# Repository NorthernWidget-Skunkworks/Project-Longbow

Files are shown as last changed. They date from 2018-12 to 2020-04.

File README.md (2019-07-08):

# Project-Longbow
Eagle files for a RS-485 range extender system, designed to go between I2C and RS-485 (or simply convert RS-485 to UART. Designed to work in unison with TP-Downhole Longbow system from Northern Widget

<br>
<br />This work is licensed under a <a rel="license" href="http://creativecommons.org/licenses/by-sa/4.0/">Creative Commons Attribution-ShareAlike 4.0 International License</a>.

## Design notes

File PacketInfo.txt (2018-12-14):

Packet Length:

Send:
SOF - 1
ADR - 2
RegID - 2
EOF - 1

Total: 6

Rec:
SOF - 1
ADR - 2
RegID - 2
Data - 10
Format - 1
CRC - 3
EOF - 1

Total: 19

Longbow Widget Register Map

Ctrl:
0 - Turn on UART
1 - Send, when set, input registers are written over serial
2 - Sleep mode (??)
3 - Packet validity (CRC check result)

7 - Reset

Baud:
0 ~ 8 - Baud rate setting bits (Baud Rate = Baud*1200)

I2C send data:

I2C.beginTransmission();
I2C.write(ADR);
I2C.endTransmission();

I2C.beginTransmission();
I2C.write(ADR);
I2C.endTransmission();

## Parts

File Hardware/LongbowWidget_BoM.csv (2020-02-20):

Qty | Value | Device | Package | Parts | Description | DIGIKEY | MF | MOUSER | MPN | VALUE | VALUE_PART
2 |  | TVSSM712 | SOT23-3 | D1, D2 | Generic dual channel TVS diode | CDSOT23-SM712CT-ND | Bourns |  | CDSOT23-SM712
3 | 0.1uF | C-EU0.1UFC0402 | C0402 | C3, C4, C5 | CAPACITOR, European symbol | 490-4759-1-ND | Murata |  | GCM155R71C104KA55D
2 | 100R | R-EU_100R0402 | R0402 | R1, R2 | RESISTOR, European symbol | 311-100LRCT-ND | Yageo |  | RC0402FR-07100RL |  | 100
4 | 10R | R-EU_R0603 | R0603 | R10, R11, R12, R13 | RESISTOR, European symbol | 541-10.0SCT-ND | Vishay |  | CRCW060310R0FKEAHP |  | 10
5 | 10k | R-EU_10KR0402 | R0402 | R3, R4, R5, R8, R9 | RESISTOR, European symbol | 311-10KJRCT-ND | Yageo |  | RC0402JR-0710KL |  | 10k
2 | 1uF | C-EU1UFC0603 | C0603 | C1, C2 | CAPACITOR, European symbol | 490-10479-1-ND | Murata |  | GRM188R61C105KA12D
1 | ATTINY441/841VQFN | ATTINY441/841VQFN | VQFN-20 | U$2 | ATtiny841/441 8 bit AVR Microcontroller | ATTINY841-MMHRCT-ND | Atmel |  | ATTINY841-MMHR
1 | AVRISP1.27MM | AVRISP1.27MM | 2X3_1.27 | ISP1 | AVR ISP HEADER
2 | CONN_6SCREW_2.54 | CONN_6SCREW_2.54 | 1X06_SCREW | J0, J1 | Genaric 6 pin header | ED10565-ND | OnShore |  | OSTVN06A150
1 | DMG3404 | MOSFET-NCH-DMG3404L | SOT23-3 | Q2 | N-channel MOSFETs | DMG3404L-7DICT-ND | Diodes Incorporated |  | DMG3404L-7 | DMG3404
2 | JUMPER-SMT_2_NO_SILK | JUMPER-SMT_2_NO_SILK | SMT-JUMPER_2_NO_SILK | JP1, JP2 | Normally open jumper
1 | MIC94090C6 | MIC94090C6 | SC-70_6 | U$1 | MIC94090 - Hight Side Load Switch | 576-3484-1-ND | Microchip |  | MIC94090YC6-TR
1 | NWLOGO_MED | NWLOGO_MED | NWLOGO_MED | U$4 | Medium-sized Northern Widget logo
1 | SN65HVD33RHL | SN65HVD33RHL | VQFN-20_POWER | U2 | SN65HVD33 - Full Duplex RS-485 Tranciver, with output enable | 296-24087-1-ND | TI |  | SN65HVD33RHLR
1 | TPS7A0533DBV | TPS7A0533DBV | SOT23-5 | U1 | TPS7A05* - Ultra Low Power Low Dropout Linear Regulator | 296-TPS7A0533PDBVRCT-ND | TI | 595-TPS7A0533PDBVR | TPS7A0533PDBVR
2 | TXS0102DQM | TXS0102DQM | DQM_R-PX2SON-N8 | U$3, U$6 | TXS0102 - 2 Channel Bidirectional Voltage Level Translator | 296-28435-1-ND | TI |  | TXS0102DQMR

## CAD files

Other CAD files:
3Dprint/StencilMount_LongbowWidget_v1.STL

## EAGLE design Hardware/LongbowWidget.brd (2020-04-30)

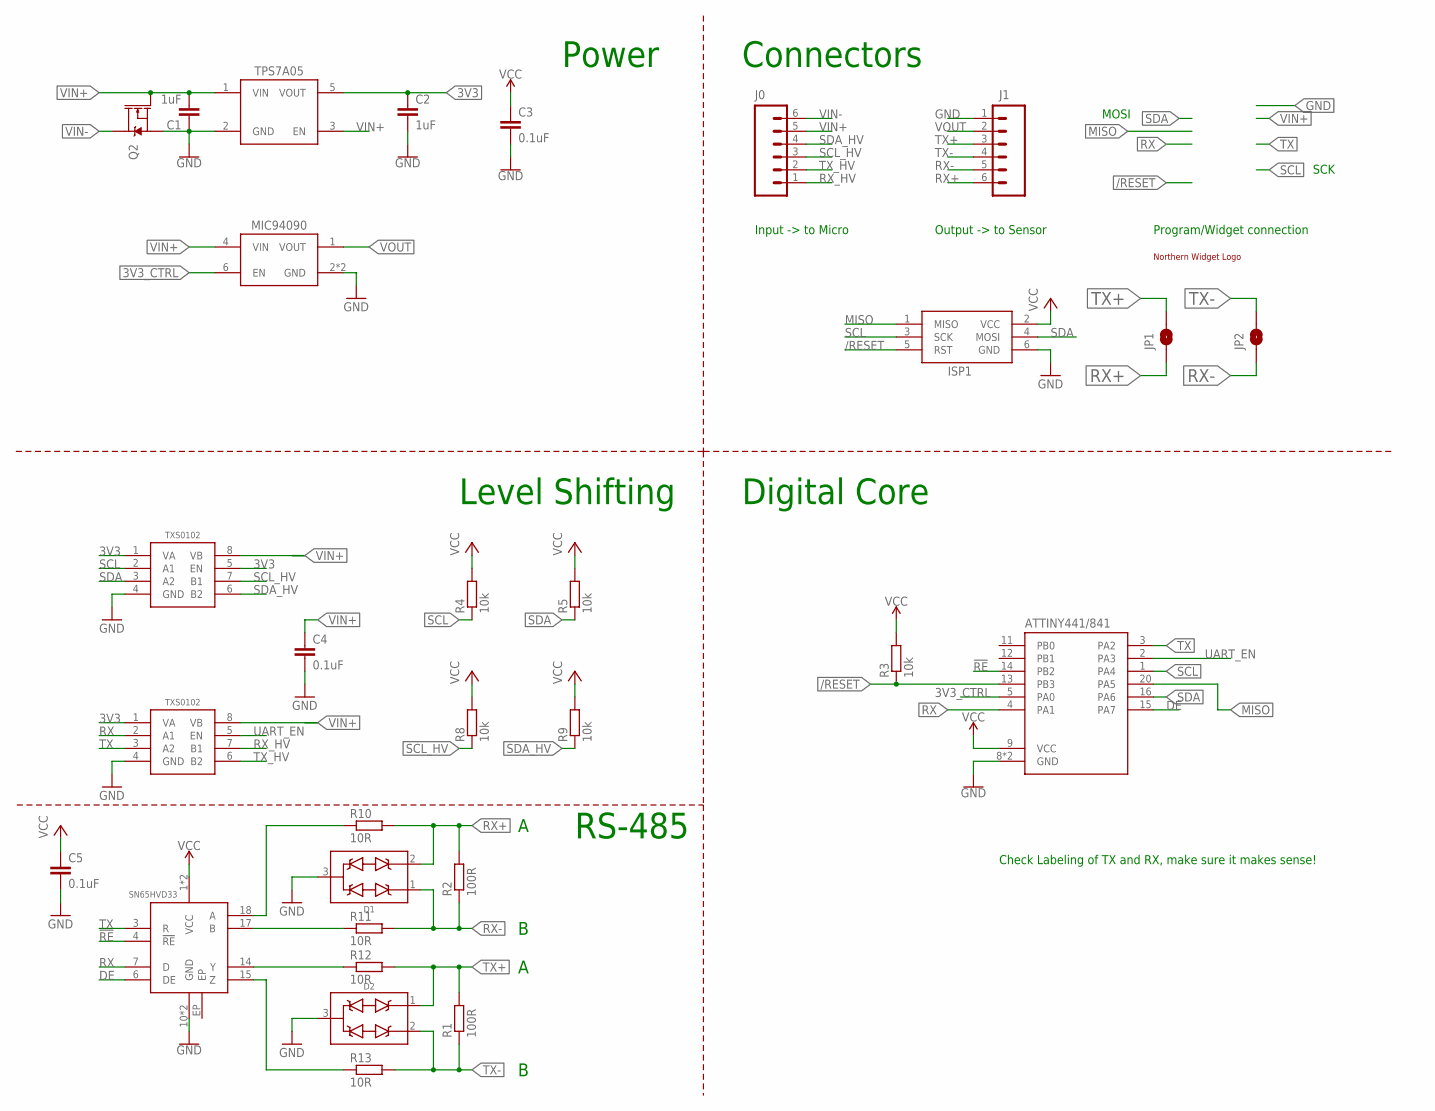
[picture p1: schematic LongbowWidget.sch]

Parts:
C1, C2: 1uF; C0603
C3, C4, C5: 0.1uF; C0402
D1, D2: TVSSM712; SOT23-3
ISP1: AVRISP1.27MM; 2X3_1.27
J0, J1: CONN_6SCREW_2.54; 1X06_SCREW
JP1, JP2: JUMPER-SMT_2_NO_SILK; SMT-JUMPER_2_NO_SILK
Q2: DMG3404; SOT23-3
R1, R2: 100R; R0402
R3, R4, R5, R8, R9: 10k; R0402
R10, R11, R12, R13: 10R; R0603; MPN CRCW060310R0FKEAHP; DIGIKEY 541-10.0SCT-ND
U1: TPS7A0533DBV; SOT23-5; DIGIKEY 296-TPS7A0533PDBVRCT-ND
U2: SN65HVD33RHL; VQFN-20_POWER
U$1: MIC94090C6; SC-70_6
U$2: ATTINY441/841VQFN; VQFN-20
U$3, U$6: TXS0102DQM; DQM_R-PX2SON-N8
U$4: NWLOGO_MED

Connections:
3V3: C2.1, C3.1, C5.1, ISP1.2 (VCC), R3.2, R4.2, R5.2, U1.5 (VOUT), U2.1 (VCC), U2.20 (VCC), U$2.9 (VCC), U$3.1 (VA), U$3.5 (EN), U$6.1 (VA)
3V3_CTRL: U$1.6 (EN), U$2.5 (PA0)
!RE: U2.4 (!RE), U$2.14 (PB2)
/RESET: ISP1.5 (RST), R3.1, U$2.13 (PB3)
DE: U2.6 (DE), U$2.15 (PA7)
GND: C1.1, C2.2, C3.2, C4.2, C5.2, D1.3 (COM), D2.3 (COM), ISP1.6 (GND), J1.1, Q2.2 (S), U1.2 (GND), U2.10 (GND), U2.11 (GND), U$1.2 (GND), U$1.5 (GND), U$2.8 (GND), U$2.EP (GND), U$3.4 (GND), U$6.4 (GND)
MISO: ISP1.1 (MISO), U$2.20 (PA5)
unnamed: R10.1, U2.18 (A)
unnamed: R11.1, U2.17 (B)
unnamed: R12.1, U2.14 (Y)
unnamed: R13.1, U2.15 (Z)
RX: U2.7 (D), U$2.4 (PA1), U$6.2 (A1)
RX+: D1.2 (D2), J1.6, JP1.1, R2.2, R10.2
RX-: D1.1 (D1), J1.5, JP2.1, R2.1, R11.2
RX_HV: J0.1, U$6.7 (B1)
SCL: ISP1.3 (SCK), R4.1, U$2.1 (PA4), U$3.2 (A1)
SCL_HV: J0.3, R8.1, U$3.7 (B1)
SDA: ISP1.4 (MOSI), R5.1, U$2.16 (PA6), U$3.3 (A2)
SDA_HV: J0.4, R9.1, U$3.6 (B2)
TX: U2.3 (R), U$2.3 (PA2), U$6.3 (A2)
TX+: D2.1 (D1), J1.3, JP1.2, R1.2, R12.2
TX-: D2.2 (D2), J1.4, JP2.2, R1.1, R13.2
TX_HV: J0.2, U$6.6 (B2)
UART_EN: U$2.2 (PA3), U$6.5 (EN)
VIN+: C1.2, C4.1, J0.5, Q2.1 (G), R8.2, R9.2, U1.1 (VIN), U1.3 (EN), U$1.4 (VIN), U$3.8 (VB), U$6.8 (VB)
VIN-: J0.6, Q2.3 (D)
VOUT: J1.2, U$1.1 (VOUT)

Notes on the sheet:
Check Labeling of TX and RX, make sure it makes sense!
MOSI
SCK
Power
Connectors
Level Shifting
Digital Core
RS-485
Input -> to Micro
Output -> to Sensor
Program/Widget connection

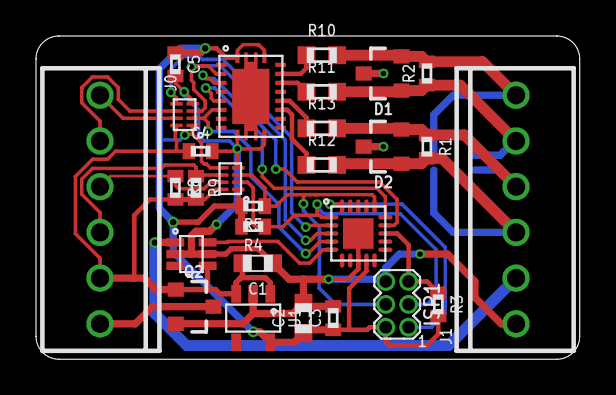
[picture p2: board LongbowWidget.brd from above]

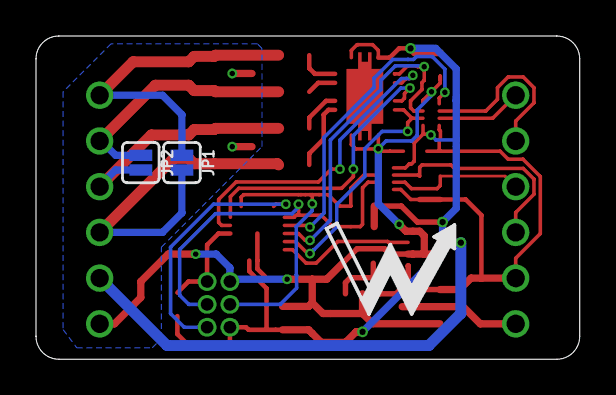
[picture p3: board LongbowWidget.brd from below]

Board: 2 copper layers, 30.2 x 18.0 mm, 31 parts (3 on the bottom side), 27 nets.

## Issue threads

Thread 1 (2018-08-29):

Fix polarity between RS-485 module and ATTINY

bschulz1701, 2018-08-29:
Switch polarity of TX and RX between ATTINY and RS-485 module, meaning Pin 2 of SN65HVD30 should be connected to Pin 11 on ATTINY841, and alternately, Pin 3 on SN65HVD30 should be connected to Pin 12 on the ATTINY841. Connections from SN65HVD30 to header should remain the same

bschulz1701, 2018-09-07:
Fixed connection polarity, closing issue pending testing... Fingers crossed it all works correctly in hardware!

Closed 2018-09-07.

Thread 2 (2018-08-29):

Add reset resistor for ATTINY on Widget module

bschulz1701, 2018-08-29:
Add a pullup resistor on the reset line of the ATTINY on the Longbow Widget module

bschulz1701, 2018-08-30:
Erroneous, the Widget has a pullup, it is the TP-Downhole which does not!

Closed 2018-08-30.

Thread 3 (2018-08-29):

Change/update labels on Widget module

bschulz1701, 2018-08-29:
Change labels like "5v" to more generic names "Vin" and use reverse polarity markings

PS. Add reverse polarity protection!

bschulz1701, 2018-09-07:
Added revised/updated labels (reverse polarity, generic voltage names, etc)

Closed 2018-09-07.

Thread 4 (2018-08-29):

Add power MOSFET to Widget module to allow shutoff of connected device

bschulz1701, 2018-08-29:
Add a MOSFET to allow the Widget module to shutoff power to the connected device, this will allow for reducing power consumption, as well as allowing for the Widget to trigger a reset operation

bschulz1701, 2018-09-07:
Added FET and driver in series between input and output power which is controlled by the ATTINY841 GPIO

Closed 2018-09-07.

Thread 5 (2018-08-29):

Fix the layout of the universal header breakout board

bschulz1701, 2018-08-29:
The programming header crashes with the Widget when connecting to the Longbow widget. Make it not do that.

Try not to suck this time...

bschulz1701, 2018-09-07:
Fixed by making version which supports pogo pins, and inverting the programming connector so it is on the opposite side of the pogo pins/universal connector to avoid crashing issue. This is done at the cost of having a programming connector mounted AND breadboard breakout mounted at the same time, but with the benefit of size

Closed 2018-09-07.

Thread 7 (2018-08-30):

Add voltage level conversion to input

bschulz1701, 2018-08-30:
Add a buffer to the TX/RX input lines (like the SN74LV1T34) in order to make inputs 5v tolerant, and to drive the output at the same voltage as VIN

bschulz1701, 2018-09-07:
Added pair of LSF0102 bi-directional level shifters for both I2C lines and UART lines, which have the Logger side shifted up to Vcc and operate on board at the 3v3 level

Closed 2018-09-07.

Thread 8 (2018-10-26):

FIRMWARE: Fix EEPROM reset issue

bschulz1701, 2018-10-26:
## Problem:
When device it power cycled, EEPROM is randomly reset/corrupted. Random in the sense that it sometimes happened after a few (2~3) power cycles, sometimes would run for 20 cycles before an issue presented itself.

### Current State:
Issue present on ALPHA firmware for Longbow Widget (as of b9a61449dca976ff6ceeb9f0c46e94d493d3b9aa) problem resolved via hotfix in 6a7682a8256895bdf539f26d36cfa6cb813115d1, but this also removed ability to configure baud rate and address on the fly.

### Previous work:
Tried adjusting fuses to turn on BOD, did not fix problem
Removed ability to set EEPROM over I2C, left only the initial write for if the EEPROM was not initialized, did not fix problem
Removed all code which wrote to the EEPROM, **did** fix problem, but obviously at expense of several features.

### Going forward:
I have come to suspect that random code is being executed during the wakeup and shutdown cycles, while this is not normally and issue, when an EEPROM write command is called and the variable which it is writing is not initialized, a problem occurs. Hard to prove this is the issue exactly. However I think I came pretty close: had a function which wrote to the EEPROM, this function was NEVER called by the program. There were NO lines which referenced the `EEPROM` in the code except in that function. The EEPROM still became randomly corrupted after repeated power cycling.
Not sure exactly how to fix this issue, perhaps some kind of atomic write? But if code is truly being executed randomly, I am not sure this would work either. Seems like a big problem overall, so need to try to figure it out.

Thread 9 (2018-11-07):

FIRMWARE: Fix address set over I2C

bschulz1701, 2018-11-07:
Fix setting of TP-Downhole address over I2C through widget. The problem exists either in the Widget Firmware, or the Longbow Interface I2C sketch.

### Issue:
As of 86a754887dc891d7230b5af8335212d345bb8b25
When you call the `SetAddress()`, the address of the TP-Downhole is not set. This issue occurs using either `SetAddress(14, 99)` or `SetAddress(14, 13)` where the current address = 13, and the desired address = 14.

### Testing:
`SetAddress()` function is (as of testing)
```C
uint8_t SetAddress(uint8_t NewAdr, uint8_t Adr)
{
	char ADR_Temp[2] = {0};
	char ADR_New[2] = {0};
	char AddressReg[2] = {'9', '9'};
	IntToArray(ADR_Temp, Adr); //Convert Adr to char array
	IntToArray(ADR_New, NewAdr); //Convert new address to char array

  Serial.print(AddressReg[0]); //DEBUG!
  Serial.println(AddressReg[1]); //DEBUG!
	SendData(0, 1);  //Turn on UART
	SendData(1, ADR_Temp, 2);  //Load I2C register
	SendData(2, AddressReg, 2);  //Load downhole register
	SendData(3, ADR_New, 2);  //Load data
	SendData(0, 3); //Set send bit, keep UART on
}
```

Checked TP-Downhole info using status pin, when calling `SetAddress`, the TP-Downhole should receive a register ID of 99, where `RegID = 99`, using that status pin on the TP-Downhole I found that when `SetAddress` was called, the condition `if(RegID == 99)` was never met.

Tested to see if problem existed in the TP-Downhole firmware, tried using simple UART through Longbow Widget, and sent the following message at 4800 baud `[139914]` this successfully set the address to 14, and worked using `[999914]` as well (general address call) and the status pin successfully indicated that the condition `RegID == 99` was true (this was expected, but verifies that the status indication was working correctly when it gave the negative result previously). This indicates that the issue lies either with the `Longbow_Interface_I2C.ino` sketch or with the `v0_1_0.ino` firmware for the Longbow Widget. My intuition is that it is with the test sketch, but have not been able to verify this yet.

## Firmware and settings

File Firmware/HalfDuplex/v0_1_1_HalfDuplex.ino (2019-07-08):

/******************************************************************************
v0_1_1.cpp
Firmware to be placed on the Longbow Widget microcontroller to interface with Longbow type comunications
Bobby Schulz @ Northern Widget LLC
12/13/2018
https://github.com/NorthernWidget-Skunkworks/Project-Longbow

Firmware Version: 0.1.1
Compatable Hardware: v0.2, NOT compatable with v0.1

This code allows the Widget to send register read and write commands over I2C, which are passed on via RS485.

"I feel that I have at last struck the solution of a great problem—and the day is coming when telegraph wires will be laid on to houses 
just like water or gas—and friends converse with each other without leaving home."
-Alexander Graham Bell

Distributed as-is; no warranty is given.
******************************************************************************/

/**********
Dev Notes:
- Does not support variable address and baud, EEPROM problem not yet solved 
- Fixed data corruption issue with v0.2 hardware
***********/

#include <Wire.h>
#include <EEPROM.h>

volatile uint8_t ADR = 0x22; //FIX! Make address user settable 

const uint8_t Vout_Ctrl = 10; //external voltage switch controlled by pin 10, active low
const uint8_t RE = 2; //Read pin enable for SN65HVD33, active low
const uint8_t DE = 3; //Write pin enable for SN65HVD33, active high
const uint8_t UART_EN = 7; //External UART enable, active high

//FIX in/out nomenclature 

#define UART_ON 0x01  //Bitmask for turning UART on
#define DATAWRITE 0x02  //Bitmask for data write of Crtl register 
#define RESET 0x80 //Bitmask for reset command

#define SOF '['  //Define Start Of Frame character
#define EOF ']'  //Define End Of Frame character 

volatile uint8_t Ctrl = 0; //Control register to determine function of device 
volatile uint8_t Baud = 4; //Used to set baud rate, 4800 by default, FIX!
volatile char ADR_In[2] = {0};  //Input address
volatile char RegID_In[2] = {0}; //Input register ID
volatile char Data_In[10] = {0}; //Input data
volatile char Format_In = 0;
volatile char CRC_In[3] = {0}; //Input CRC check

volatile char ADR_Out[2]; //Output address (from slave)
volatile char RegID_Out[2] = {0}; //Output register ID (from slave)
volatile char Data_Out[10] = {0}; //Output data (From slave)
volatile char Format_Out = 0; //Output data fromatter (from slave)
volatile char CRC_Out[4] = {0}; //Output crc check (from slave)

volatile uint8_t Reg = 0; //Used to point to which register to read out

bool UartActive = false; //Used to keep track if UART is on

void setup() 
{
	pinMode(Vout_Ctrl, OUTPUT); //Make power control pin an output
	pinMode(RE, OUTPUT); //Make read enable output
	pinMode(DE, OUTPUT);  //Make write enable output
	pinMode(UART_EN, OUTPUT); //Make UART Enable an output

	digitalWrite(Vout_Ctrl, HIGH); //Turn power on by default
	digitalWrite(RE, HIGH);  //Disable RS485 read by default (master default)
	digitalWrite(DE, HIGH);  //Enable RS485 write by default
	digitalWrite(UART_EN, HIGH); //Enable external UART by default

	// if(EEPROM.read(0x00) != 'L') {  //If EEPROM is not initialized, like on initial firmware load
        // EEPROM.write(0x01, ADR);  //Set default address value
        // EEPROM.write(0x02, Baud);  //Set default baud value
        // EEPROM.write(0x00, 'L');  //Set initialization flag for EEPROM
    // }
    // else {  //Normally, read address from EEPROM on startup
        ADR = EEPROM.read(0x01);
        Baud = EEPROM.read(0x02);
    // }

	Wire.begin(ADR); //Begin I2C with given slave address //FIX! respond with general address call to to allow to set address to other values
	TWSAM = 0x01; //Allow for general address call, set secondary address to 0x00, set bit to allow matching on this address

	Wire.onRequest(requestEvent);     // register event
	Wire.onReceive(receiveEvent);
}

void loop() 
{
	digitalWrite(RE, LOW);  //Enable RS485 read 
	digitalWrite(DE, LOW);  //Disable RS485 write
	//FIX add single read and no reading qualifiers //REPLACE!
	if(Serial.read() == SOF) {  //If anything is available to read

		while(Serial.available() < 4) {  //wait for mandatory data (ADR and Register ID) //FIX add timeout!
			delay(1);
		}

		ADR_Out[0] = Serial.read();  //Read in address
		ADR_Out[1] = Serial.read();

		delay(20);  //Garbage required delay, will be tracked down and terminated with extreme prejudice when time allows...
		// Serial.print("A0 = "); Serial.println('1');//Serial.println(ADR_Out[0]);  //DEBUG!

		RegID_Out[0] = Serial.read();  //Read in register ID
		RegID_Out[1] = Serial.read();

		int i = 0; //Counter 
		memset(Data_Out, 0, 10); //Clear Data_Out manually
		while(Serial.peek() < 65) {  //Read until formating character  //FIX add timeout, and out of range indicatior
			Data_Out[i++] = Serial.read(); 
		}

		unsigned char TestCRC = GetCRC(Data_Out, i);  //Calculate CRC given data packet 

		while(Serial.available() < 1) {  //Wait for formatting byte
			delay(1);
		}

		Format_Out = Serial.read();  //Read formatting character in

		i = 0;  //Clear counter to reuse
		memset(CRC_Out, 0, 4); //Clear CRC_Out manually

		while(Serial.available() < 2) {  //Wait for at least single digit CRC and EOF character 
			delay(1);
		}
		delay(20);
		
		CRC_Out[i++] = Serial.read();
		while(Serial.peek() != EOF) { //Read in CRC of variable (1~3 characters) length, looking for EOF character
			CRC_Out[i++] = Serial.read();
		}
		CRC_Out[i] = '\0';  //manually add terminator to string to that it can be parsed with strol


		Ctrl = Ctrl & 0xF7; //Clear bit 3, packet validity bit
		if(TestCRC != strtol(CRC_Out, NULL, 10)) Ctrl = Ctrl | 0x08; //Set packet error bit by checking calculated value against the converted value from message
	}

	if((Ctrl & DATAWRITE) == DATAWRITE) {  //If control bit is set, print registers to output
		digitalWrite(RE, HIGH);  //Disable RS485 read 
		digitalWrite(DE, HIGH);  //Enable RS485 write 
    	Serial.print(SOF);  //Print SOF to indicate message to come
    	PrintArray(ADR_In, 2);  //Print address
    	PrintArray(RegID_In, 2);  //print Register ID

    	if(Data_In[0] != 0) {  //Test if data is present, if so, write it out
    		PrintArray(Data_In, 10); //Print data array
    		PrintArray(CRC_In, 3);   //Print CRC array
    	}
    	Serial.print(EOF);  //Print end of message indicator 
    	Serial.print("\n"); //Print formatting character
    	Ctrl = Ctrl & 0xFD; //Clear data write bit  //FIX to be modular with masking!
    	digitalWrite(RE, LOW);  //Enable RS485 read 
		digitalWrite(DE, LOW);  //Disable RS485 write
	}

	if((Ctrl & UART_ON) == 1 && !UartActive) {  //Turn on UART only when directed to over I2C
		digitalWrite(DE, LOW); //Disable RS-485 output before adjusting Serial config
		digitalWrite(UART_EN, LOW); //Disable external UART to prevent clash 
		Serial.begin(Baud*1200);  //Begin Serial at the user defined speed
		digitalWrite(DE, HIGH); //Re-enable RS-485 output once new serial configuration setup
		UartActive = true; //Set uart running flag
	}

	if((Ctrl & UART_ON) == 0 && UartActive) {  //If UART ON bit is cleared, and UART is running, turn off UART
		Serial.end(); //Turn off serial
		UartActive = false; //Clear uart running flag
		digitalWrite(UART_EN, HIGH); //Re-enable external UART once on board serial has been turned off
	}

	if((Ctrl & RESET) == RESET) {  //If reset bit if set
		//Turn off RS485 to prevent voltage leak sensor 
		digitalWrite(RE, HIGH); //Turn recieve off //DEBUG!
		digitalWrite(DE, LOW); //Turn transmit off  //DEBUG!
		//Once RS485 is turned off, turn off main external power
		digitalWrite(Vout_Ctrl, LOW);  //Turn external power off
		delay(100);  //Wait a jiffy (1/60 second)
		//Startup in inverse sequence to prevent inappropriate power flow
		digitalWrite(RE, HIGH); //Leave off recieve  //DEBUG!
		digitalWrite(DE, HIGH); //Turn on transmit  //DEBUG!
		digitalWrite(Vout_Ctrl, HIGH);  //Turn on external power
		delay(100);
		while(Serial.read() != 'r') { //Wait until recived conformation of reset  //FIX add timeout!
			Serial.print("!"); //Print escape character
			Serial.print("!"); //Print escape character //DEBUG!
		}
    	Ctrl = Ctrl & 0x7F; //Automatically clear reset bit after reset has been completed 
    	digitalWrite(RE, LOW);  //Enable RS485 read 
		digitalWrite(DE, LOW);  //Disable RS485 write
	}
	delay(1);

}

void PrintArray(char *Data, uint8_t Len) {  //Helper function for printing subset of array
	for(int i = 0; i < Len; i++) {
		Serial.print(Data[i]);
	}
}

unsigned char GetCRC(const unsigned char * data, const unsigned int size)  //CRC calculation
//Using CRC-8 From Dallas/Maxim group, with a polynomial of 0x8C, and an even parity (same as 1 wire bus)
{
    unsigned char crc = 0;
    for ( unsigned int i = 0; i < size; ++i )
    {
        unsigned char inbyte = data[i];
        for ( unsigned char j = 0; j < 8; ++j )
        {
            unsigned char mix = (crc ^ inbyte) & 0x01;
            crc >>= 1;
            if ( mix ) crc ^= 0x8C;
            inbyte >>= 1;
        }
    }
    return crc;
}

void requestEvent()  //Respond to request for data
{	
	switch(Reg) {
		case 0:  //Write out control byte
			Wire.write(Ctrl);
			break;

		case 1:  //Write out address value
			Wire.write(ADR_Out[0]);
			Wire.write(ADR_Out[1]);
			break;

		case 2:  //Write out register ID
			Wire.write(RegID_Out[0]);
			Wire.write(RegID_Out[1]);
			break;

		case 3:  //Write out data
			for(int i = 0; i < 10; i++) {
				Wire.write(Data_Out[i]);  //write all data out 
			}
			break;

		case 4: //Write out format character
			Wire.write(Format_Out); 
			break;

		case 5:  //Write out CRC
			for(int i = 0; i < 3; i++) {
				Wire.write(CRC_Out[i]);  //write all data out 
			}
			break;

		case 96:  //Write out baud rate
			Wire.write(Baud); //Return baud rate
			break; 

		case 98:  //Write out address
			Wire.write(ADR); //Return address
			break;
	}
}

void receiveEvent(int DataLen) //respond to recipt of data
{
	int i = 0; //Initialize general counter (switch cases get anrgy about redefinition)
	Reg = Wire.read(); //Read first byte of data, this will determine what is being sent 
	if(DataLen > 1) {
		switch(Reg) {
			case 0:  //Read in control byte
				Ctrl = Wire.read(); //DEBUG!
				break;

			case 1:  //Read in address value
				ADR_In[0] = Wire.read();
				ADR_In[1] = Wire.read();
				break;

			case 2:  //Read in register ID
				RegID_In[0] = Wire.read();
				RegID_In[1] = Wire.read();
				break;

			case 3:  //Read in data 
				i = 0; //Counter
				memset(Data_In, 0, 10); //Manually clear Data_In, in case new data is shorter than previous data
				while(Wire.available() > 0) {  //FIX use length of data instead??
					Data_In[i++] = Wire.read();  //read all data into register 
				}
				break;

			case 4:  //Read in formatting character 
				Format_In = Wire.read();
				break;

			case 5:  //Read in CRC code
				i = 0; 
				memset(CRC_In, 0, 3); //Manually clear CRC_In, in case new crc is shorter than previous
				while(Wire.available() > 0) {  //FIX use length of data instead??
					CRC_In[i++] = Wire.read();
				}
				break;

			case 97:  //Read in baud rate setting
				// EEPROM.write(0x02, Wire.read()); //Update EEPROM
				break;

			case 99:  //Read in address setting 
				// EEPROM.write(0x01, Wire.read()); //Update EEPROM
				break;

			default:  //Clear buffer by default
				while(Wire.available()) {
					Wire.read();
				}
				break;
		}
	}
}

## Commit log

2018-03-01 Initial comit of Longbow widget, Univerisal header breakout
    [Longbow Widget.brd, Longbow Widget.sch, UniversalBoardBreakout.brd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]
2018-08-28 Added notes for improvments
    Added comment notes for improvements:
    Read values from EEPROM for baud and address
    Set address (I2C) via response to general address call
    Make baud rate user settable using the control register
2018-08-29 Improved Longbow Widget Firmware, added interface software
    Added user settable features to the longbow widget firmware, added CRC check, etc. Firmware is in BETA stage, nearly ready for wide scale testing.
    Created a software interface demo for communicating with the longbow widget from an Arduino
    Both files need cleanup, some commenting and aesthetic changes, functionally 90% there
2018-08-30 Updated Longbow Widget schematic, very preliminary board layout
    Added fixes for many of the issues to the schematic, made very preliminary board layout
    Likely to add some kind of transient protection to Longbow Widget, have left space on preliminary board layout to add in later
    [Longbow Widget.brd, Longbow Widget.sch]
2018-08-31 Preliminary layout for Longbow Widget complete
    Needs cleanup and changes to silk screen before review, should be nearly functional (should add polygon pours for power on input side). Also added preliminary BOM, which requires update with new part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
    [Longbow Widget.brd, Longbow Widget.sch, Longbow Widget_BOM.csv]
2018-09-05 Cleaned up Widget
    Cleaned up layout of widget, adjusted silkscreen, fixed pinout issue, generated final gerbers, ready for prototype
    [Longbow Widget.brd, Longbow Widget.sch]
2018-09-06 Final designs for Longbow Widget v0.1 and Universal Breakout Pogo board
    Added final design (minor silk screen additions) of the Longbow widget, also designed a modified Universal breakout which has support for pogo pins. Generated final gerbers for both as well
    [Longbow Widget.brd, Longbow Widget.sch, UniversalBoardBreakout_Pogo.brd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]
2018-09-07 Fixed part numbers on Longbow Widget, generated new BOMs
    Parts list is updated and fully auto generating
    [Longbow Widget.brd, Longbow Widget.sch, Longbow Widget_BOM.csv]
2018-09-07 Fixed part number for RS-485 driver
    Fixed the part number in the BOM for the RS-485 driver
    [Longbow Widget.brd, Longbow Widget.sch, Longbow Widget_BOM.csv]
2018-09-10 Updated Longbow Widget to use new Frames
    Updated to used new frames without Creative Commons text (caused issues)
    [Longbow Widget.brd, Longbow Widget.sch]
2018-09-27 Added reset and set address ability
    Added reset ability to longbow widget firmware, still needs verification with reworked hardware. Currently data lines do not shut off so only browns out TP-Downhole, does not force reset. Hardware improvement to Longbow Widget required to fix. Added set address ability to Longbow Interface software, testing not extensive, but seems to work fine
2018-09-29 Updated gerbers for solder stencils
    Updated folder of gerbers for longbow widget (newest gerbers were only in Zip file, so never overwrote old ones), then generated SVG (-> DXF) of paste layer to use for laser cutting solder stencil
    [Longbow Widget-bcream.dxf, Longbow Widget-tcream.dxf, Longbow Widget.dxf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]
2018-10-17 Firmware hotfix, v0.0
    Hotfix for the firmware for Longbow widget. EEPROM was randomly being overwritten/altered, removed all write to EEPROM commands to provide stability. Removed ability to set address/baud rate on the fly, need to find origin of issue and real fix. I think it has to do with the power on condition and things being written to randomly. Firmware deployed, official v0.0
2018-10-19 Updated Longbow Widget, v0.2 ready for review
    Made changes to new level shifters, RS485 driver with output shutoff, replaced mosfet with load switch, converted MCU to QFN package. Ready for final review
    [Longbow Widget.brd, Longbow Widget.sch]
2018-10-27 Longbow Widget v0.2 sent to fab
    Minor edits to silkscreen on longbow widget, v0.2 timeline, generated gerbers for Longbow Widget
    [Longbow Widget.brd, Longbow Widget.sch]
2018-11-01 Added folder system and design PDFs
    Added schematic and board PDFs for v0.2
    [Longbow Widget-bcream.dxf, Longbow Widget-tcream.dxf, Longbow Widget.brd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]
2018-12-14 Added firmware v0.1.1, packet description doc
    Added updated firmware version, v0.1.1, fixes intermittent transmission failure on v0.2 hardware
    [v0_1_1.ino]
2020-02-20 Updated to v0.3
    Minor update, added jumpers to allow for conversion to 2 wire RS485 without external jumping/connection. Made edits in Eagle, generated new gerber files and updated BoM to reflect "jumper" parts
    [Longbow Widget.brd, Longbow Widget.sch, Longbow Widget_BOM.csv]
2020-04-28 Added A and B value note in schematic
    [Longbow Widget.sch]
2020-04-30 stencil mount
    [StencilMount_LongbowWidget_v1.STL]
2020-04-30 Deprecated design files
    [Longbow Widget-bcream.dxf, Longbow Widget-tcream.dxf, Longbow Widget.dxf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]
2020-04-30 Deprecated connector for TLog
    [UniversalBoardBreakout.brd, UniversalBoardBreakout.sch, UniversalBoardBreakout_Pogo.brd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]
2020-04-30 No more accessories; no need for nested folders
    [Longbow Widget.brd, Longbow Widget.sch, Longbow Widget_BOM.csv]
2020-04-30 rm filename spaces
    [LongbowWidget.brd, LongbowWidget.sch, LongbowWidget_BoM.csv]
2020-04-30 Label A+ and B- for half duplex
    [LongbowWidget.brd]
2026-11-04 CITATION.cff: type hardware; preferred-citation type generic
    CFF 1.2.0 allows only software or dataset at the top level, so "hardware"
    fails the schema on purpose: this is a circuit-board design, not software.
    The preferred-citation (what GitHub shows) uses the valid reference type
    generic.
    Claude-Session: https://claude.ai/code/session_017F2gr2X4Cbf5cXUitE8DNF

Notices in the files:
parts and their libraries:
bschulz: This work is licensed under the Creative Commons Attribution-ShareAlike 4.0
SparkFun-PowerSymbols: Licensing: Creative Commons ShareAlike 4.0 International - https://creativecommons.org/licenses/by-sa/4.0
